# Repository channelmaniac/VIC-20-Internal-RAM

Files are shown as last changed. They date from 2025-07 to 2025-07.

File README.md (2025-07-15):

# VIC-20-Internal-RAM
An internal RAM expansion board for the VIC-20.

The VIC-20 is an interesting computer, but has an oddity in that you're limited to one cartridge at a time... Do you use memory? Do you use some other hardware interface? I thought it was a bit silly so I created an internal memory upgrade board. I also did this as a learning experience as this is my first GAL to design the equations for. 

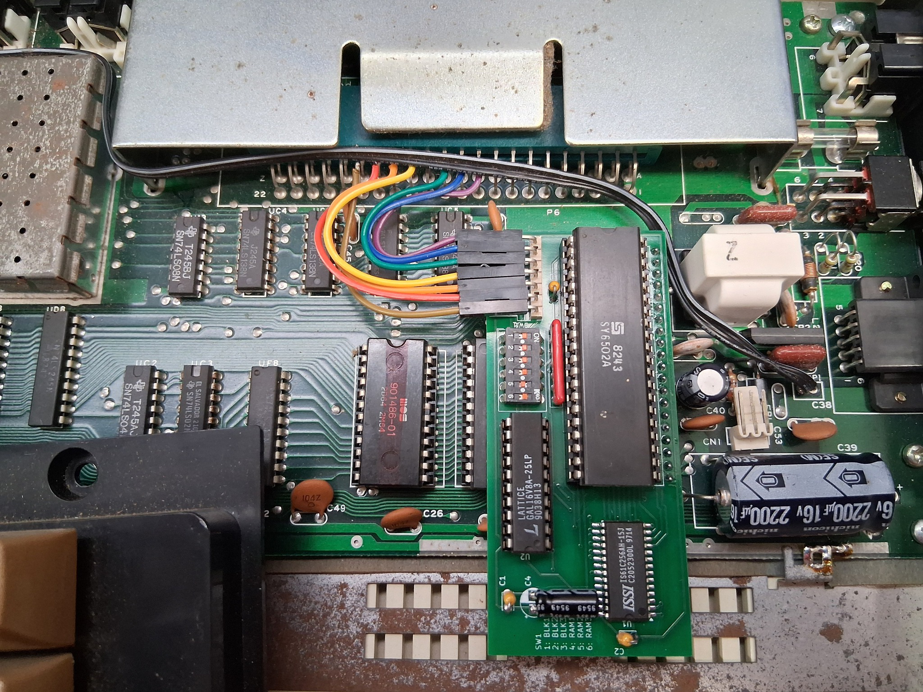
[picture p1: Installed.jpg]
VIC-20 PCB with internal RAM module installed


This board uses a single 32K x 8 SRAM chip and a bank of 6 DIP switches to enable/disable individual banks of memory using the already decoded memory bank enables on the cartridge port:

These represent the 3K expansion cartridge:
* RAM 1 = 0400 - 07FF
* RAM 2 = 0800 - 0BFF
* RAM 3 = 0C00 - 0FFF

These represent the 8, 16, and 24K cartridges:
* Block 1 = 2000 - 3FFF
* Block 2 = 4000 - 5FFF
* Block 3 = 6000 = 7FFF

The board uses a few flying wires for the signals it cannot get from the CPU which include the above mention memory bank enables from the cartridge port plus the VR/W signal off the same cartridge port.

The only shortcoming with this board is that the DIPs are internal. This can cause problems with some game cartridges, notably the ones that use Block 1, 2, and/or 3 instead of Block 5 (A000 - BFFF) for the ROM addresses. Star Trek Strategic Operations Simulator is one such cartridge that uses Block 1 address space.

The PCB is easy to build, with only one surface mount part - the SOJ packaged static RAM chip. As for the GAL, any 16V8x should work for it. I used a GAL16V8A-25 in my initial build. GALs are reusable, so no need to go buy one if you have a scrap PCB you can salvage one from. I pulled the one I used off an old 8-liner gambling PCB that I already pulled the ROMs, SRAMs, and Z80 off of for use in repairing arcade game PCBs. You can use a right angle header for the flying wires or solder wires straight to the PCB, that's up to you, but for clearance, don't use a straight header or you'll hit the keyboard above the PCB. **The pins on the header connecting to the CPU socket must be trimmed to not interfere with the placement of the CPU socket on the PCB. Also, the pins on the DIP switches, GAL, and input header need to be trimmed to clear the ROM next to the CPU.** While it's not critical to clear the ROM if you have sufficient contact with the CPU socket, It personally bugs me to see a PCB touching chips under it and not seating down level in the socket.

It has been tested in the revision of VIC-20 that runs off a DC supply. It should fit in the older revision, but has not been tested in one as of yet.

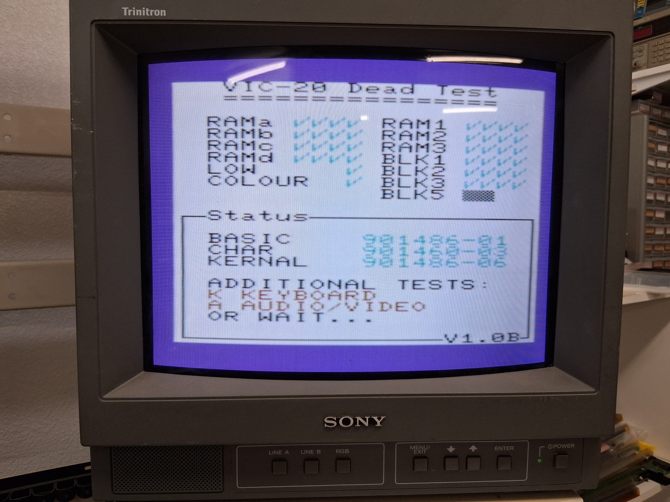
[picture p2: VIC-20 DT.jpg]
VIC-20 Dead Test Cart results for the RAM module


Inputs are labeled on the bottom silk screen. DIP switch info is on the top silk screen.

The cartridge pins for connections are easy to access and are on the upper set so no need to try to get to the bottom row for attaching the wires.

Cartridge slot pin: Signal Name
* 10 - Block 1
* 11 - Block 2
* 12 - Block 3
* 13 - Block 5 (NOT USED)
* 14 - RAM 1
* 15 - RAM 2
* 16 - RAM 3
* 17 - VR/W

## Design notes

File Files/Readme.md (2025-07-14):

# VIC-20-Internal-RAM

Here are the KiCAD files. Feel free to play with them and modify them for your usage, but please give me credit for the initial design.

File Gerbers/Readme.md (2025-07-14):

# VIC-20-Internal-RAM

Arrr! There be gerbers here. Use whichever fab suits your fancy!

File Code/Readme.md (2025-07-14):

The GAL code is stupid simple... but, hey, it's my first one to write equations for!

It basically goes like this: IF /BLK1 is low OR /BLK2 is low OR /BLK3 is low OR /RAM1 is low OR /RAM2 is low OR /RAM3 is low then /CS goes low. 

Where /BLK1, 2, and 3 and RAM 1, 2, and 3 are decoded RAM addressing signals tapped off the cartridge port and /CS is the chip select on the 32K x 8 SRAM.

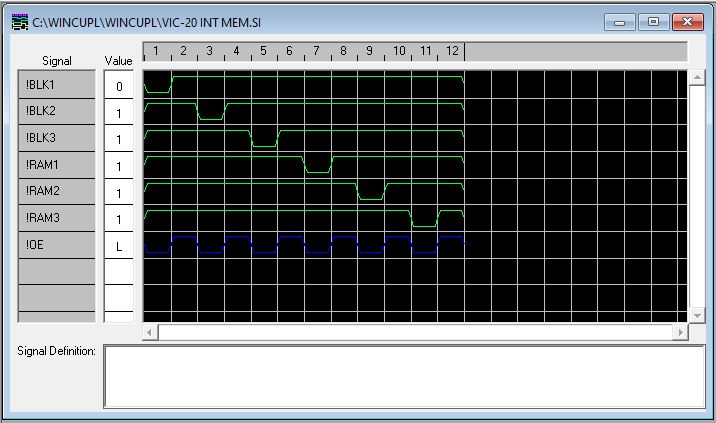
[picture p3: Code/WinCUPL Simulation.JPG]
Pic of simulation testing done in WinCUPL


What I'd like to do in a future revision is do the memory decoding in the GAL using 4 inputs from a BCD encoded switch to determine which banks to enable. This would allow for easy switching without having to disassemble the computer. It may take me a while to get that set of equations worked out. :)

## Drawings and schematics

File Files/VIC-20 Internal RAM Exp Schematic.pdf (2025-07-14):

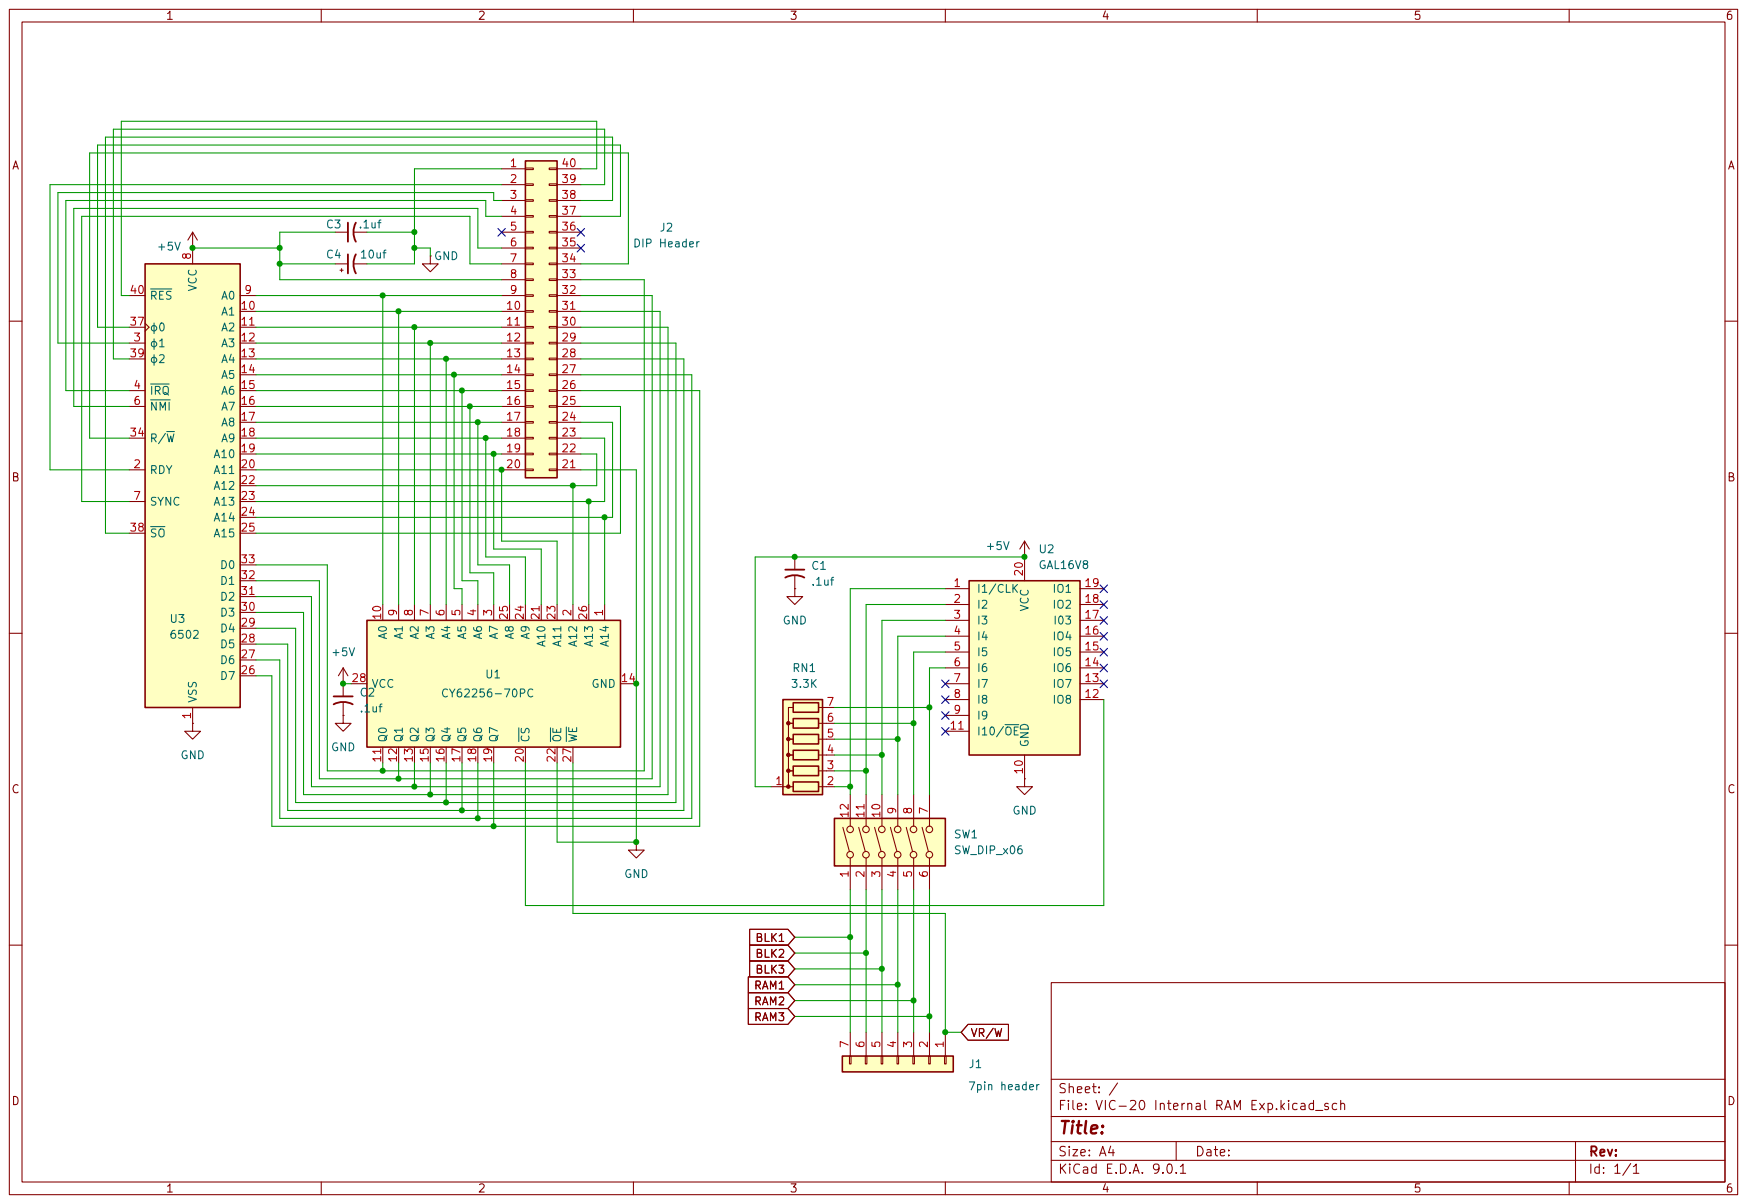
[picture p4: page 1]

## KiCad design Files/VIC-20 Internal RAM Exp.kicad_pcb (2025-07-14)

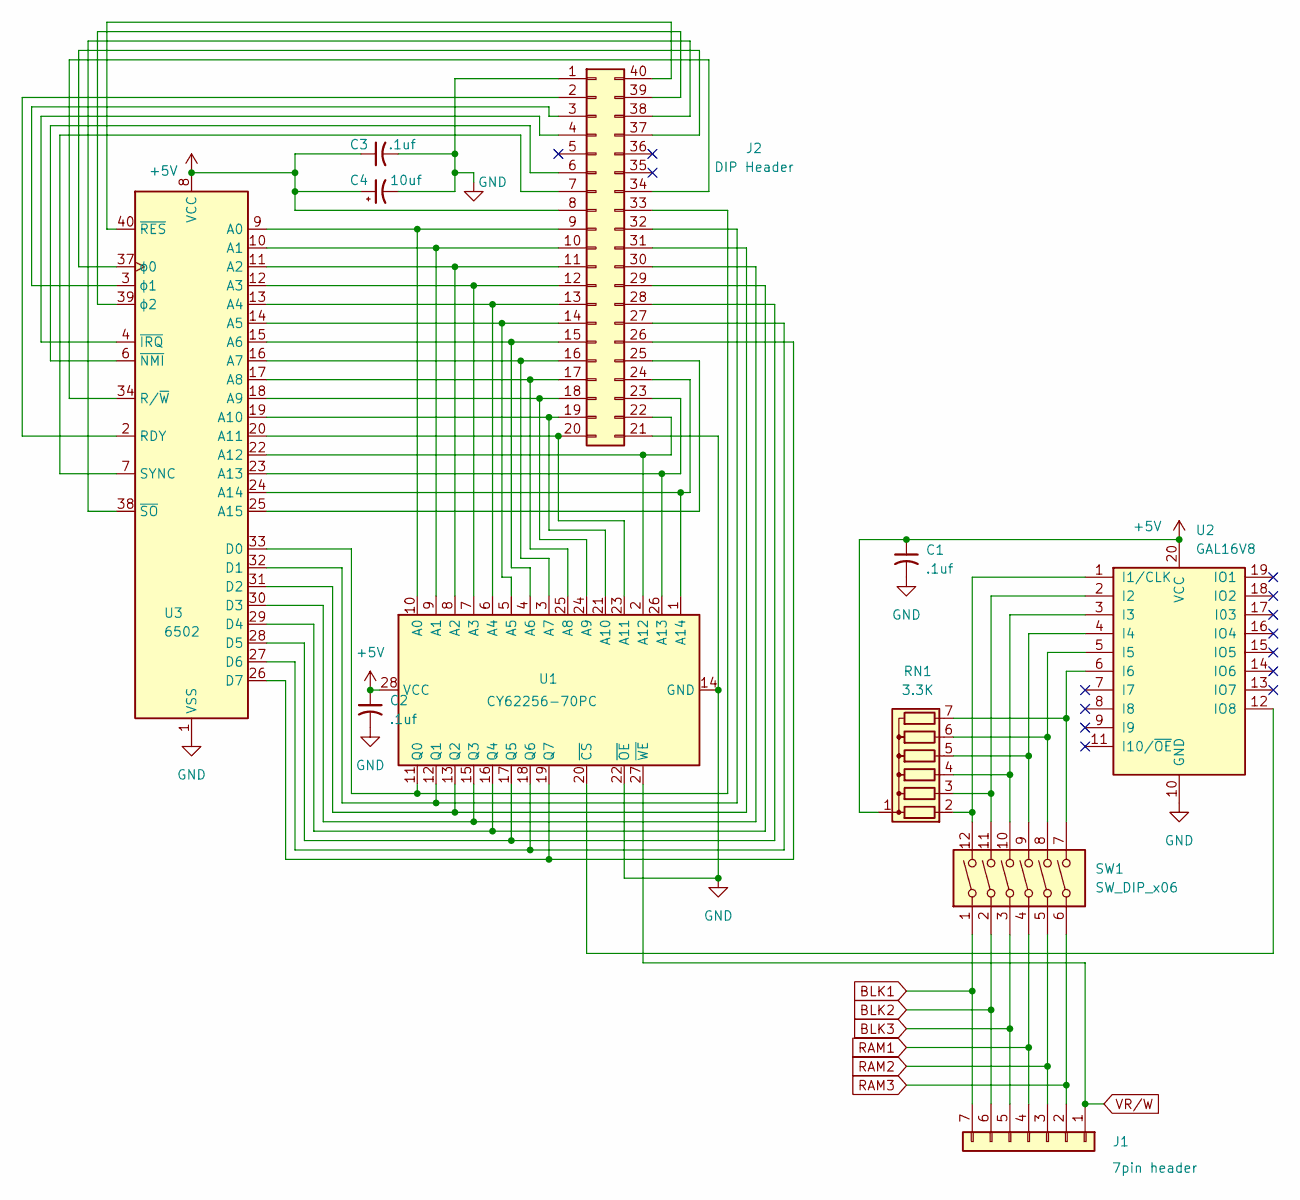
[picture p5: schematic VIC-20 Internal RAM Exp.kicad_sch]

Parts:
C1, C2, C3: .1uf; C_Disc_D3.0mm_W2.0mm_P2.50mm
C4: 10uf; CP_Radial_D5.0mm_P2.50mm
J1: 7pin header; PinHeader_1x07_P2.54mm_Horizontal
J2: DIP Header; DIP-40_W15.24mm
RN1: 3.3K; R_Array_SIP7
SW1: SW_DIP_x06; SW_DIP_SPSTx06_Slide_9.78x17.42mm_W7.62mm_P2.54mm
U1: CY62256-70PC; SOIC-28W_7.5x17.9mm_P1.27mm
U2: GAL16V8; DIP-20_W7.62mm
U3: 6502; DIP-40_W15.24mm

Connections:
+5V: C1.1, C2.1, C3.1, C4.1, J2.8, RN1.1 (common), U1.28 (VCC), U2.20 (VCC), U3.8 (VCC)
BLK1: J1.7, SW1.1
BLK2: J1.6, SW1.2
BLK3: J1.5, SW1.3
GND: C1.2, C2.2, C3.2, C4.2, J2.1, J2.21, U1.14 (GND), U1.22 (~OE), U2.10 (GND), U3.1 (VSS), U3.21 (VSS)
unnamed: J2.2, U3.2 (RDY)
unnamed: J2.3, U3.3 (ϕ1)
unnamed: J2.4, U3.4 (~IRQ)
unnamed: J2.6, U3.6 (~NMI)
unnamed: J2.7, U3.7 (SYNC)
unnamed: J2.9, U1.10 (A0), U3.9 (A0)
unnamed: J2.10, U1.9 (A1), U3.10 (A1)
unnamed: J2.11, U1.8 (A2), U3.11 (A2)
unnamed: J2.12, U1.7 (A3), U3.12 (A3)
unnamed: J2.13, U1.6 (A4), U3.13 (A4)
unnamed: J2.14, U1.5 (A5), U3.14 (A5)
unnamed: J2.15, U1.4 (A6), U3.15 (A6)
unnamed: J2.16, U1.3 (A7), U3.16 (A7)
unnamed: J2.17, U1.25 (A8), U3.17 (A8)
unnamed: J2.18, U1.24 (A9), U3.18 (A9)
unnamed: J2.19, U1.21 (A10), U3.19 (A10)
unnamed: J2.20, U1.23 (A11), U3.20 (A11)
unnamed: J2.22, U1.2 (A12), U3.22 (A12)
unnamed: J2.23, U1.26 (A13), U3.23 (A13)
unnamed: J2.24, U1.1 (A14), U3.24 (A14)
unnamed: J2.25, U3.25 (A15)
unnamed: J2.26, U1.19 (Q7), U3.26 (D7)
unnamed: J2.27, U1.18 (Q6), U3.27 (D6)
unnamed: J2.28, U1.17 (Q5), U3.28 (D5)
unnamed: J2.29, U1.16 (Q4), U3.29 (D4)
unnamed: J2.30, U1.15 (Q3), U3.30 (D3)
unnamed: J2.31, U1.13 (Q2), U3.31 (D2)
unnamed: J2.32, U1.12 (Q1), U3.32 (D1)
unnamed: J2.33, U1.11 (Q0), U3.33 (D0)
unnamed: J2.34, U3.34 (R/~W)
unnamed: J2.37, U3.37 (ϕ0)
unnamed: J2.38, U3.38 (~SO)
unnamed: J2.39, U3.39 (ϕ2)
unnamed: J2.40, U3.40 (~RES)
unnamed: RN1.2 (R1), SW1.12, U2.1 (I1/CLK)
unnamed: RN1.3 (R2), SW1.11, U2.2 (I2)
unnamed: RN1.4 (R3), SW1.10, U2.3 (I3)
unnamed: RN1.5 (R4), SW1.9, U2.4 (I4)
unnamed: RN1.6 (R5), SW1.8, U2.5 (I5)
unnamed: RN1.7 (R6), SW1.7, U2.6 (I6)
unnamed: U1.20 (~CS), U2.12 (IO8)
RAM1: J1.4, SW1.4
RAM2: J1.3, SW1.5
RAM3: J1.2, SW1.6
VR/W: J1.1, U1.27 (~WE)

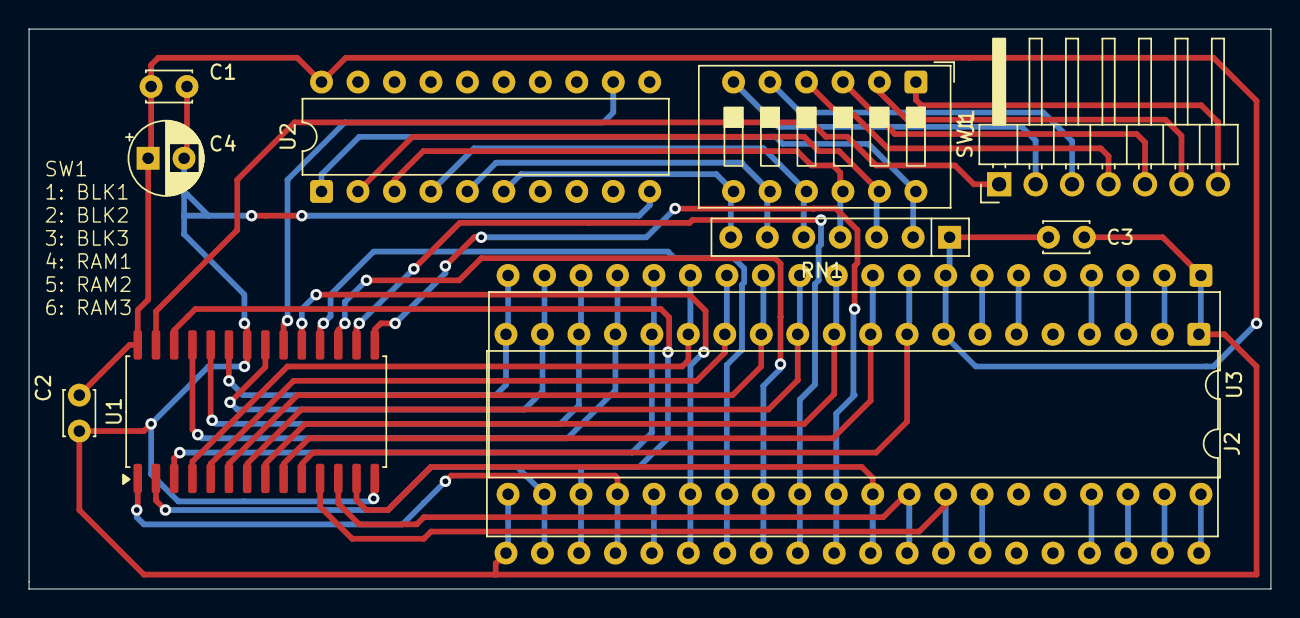
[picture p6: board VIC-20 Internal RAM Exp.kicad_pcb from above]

Board: 2 copper layers, 86.5 x 39.0 mm, 11 parts (0 on the bottom side), 50 nets.

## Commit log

2025-07-14 Add files via upload
    Added Gerbers
2025-07-14 Add files via upload
    Add BoM
